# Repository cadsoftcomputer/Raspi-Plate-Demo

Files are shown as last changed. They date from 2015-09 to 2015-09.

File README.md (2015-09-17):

# Raspi-Plate-Demo

This is an H-Bridge and IR LED Pi Hat for controlling the Rasperry Pi with an IR Remote Control.

The following sites were instrumental in setting up LIRC and having Python interface with it.
* https://piface.github.io/pifacecad/lirc.html
* http://alexba.in/blog/2013/01/06/setting-up-lirc-on-the-raspberrypi/
* http://ozzmaker.com/2013/10/24/how-to-control-the-gpio-on-a-raspberry-pi-with-an-ir-remote/

This site helped with setting up the Python script to run on boot.
* http://www.raspberrypi-spy.co.uk/2013/07/running-a-python-script-at-boot-using-cron/

The PiHat standard as defined by the Raspberry Pi Foundation
* https://github.com/raspberrypi/hats

All of the Python code was made to run under Python3 however it's likely that it will run under Python2 since the python-lirc library works in both versions of Python.

The EAGLE design files were made using V7 of EAGLE. The PiHat_Standard_Outline.lbr contains packages that conform to the PiHat standard.

For any questions or concerns contact support@cadsoftusa.com or call 954-237-0932.

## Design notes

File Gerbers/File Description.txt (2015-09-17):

cmp is the Top copper
sol is the Bottom copper
plc is the Top Silkscreen
stc is the Top stop mask
sts is the Bottom Stop mask
drd is the Drill file

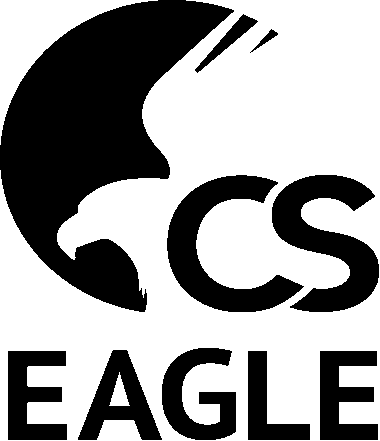
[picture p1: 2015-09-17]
eagle bw_real.bmp

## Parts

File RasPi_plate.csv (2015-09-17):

Qty | Value | Device | Package | Parts | Description | MF | MPN | OC_NEWARK
4 | 0.1u | C-USC0805 | C0805 | C4, C5 | CAPACITOR, American symbol |  | C2012X7R1H104K085AA | 04X3288
2 | 0.22u | C-USC0805 | C0805 | C2 | CAPACITOR, American symbol |  | MC0805B224M250CT | 06R3809
2 | 100 | R-US_R0805 | R0805 | R7 | RESISTOR, American symbol |  | MCHP05W4F1000T5E | 01N6987
8 | 10k | R-US_R0805 | R0805 | R1, R2, R3, R4, R5, R6 | RESISTOR, American symbol |  | RC0805FR-0710KL | 05M4535
10 | 1N4004 | 1N4004 | DO41-10 | D1, D2, D3, D4, D5, D6, D7, D8 | DIODE |  | 1N4007-E3/54 | 05R5987
4 | 1u | C-USC0805 | C0805 | C1, C3 | CAPACITOR, American symbol |  | EMK212B7105KD-T | 77M8435
2 | MCP1700 | MCP1700 | TO92 | IC3 | 1.2V, 1.8V, 2.5V, 2.8V, 3.0V, 3.3V, 5.0V | MICROCHIP | MCP1700-5002E/TO | 34M7415
2 | PIN | 2PINHEADER | 2PINHEAD | J1 | 2-PIN HEADER 2.54mm |  |  | 11P3428
2 | RAS-PI | 40W_PI_HAT_TPH | 2X20 | JP1 | PIN HEADER | SAMTEC | SSW-120-01-G-D | 50M2393
2 | SN754410 | SN754410 | DIL16 | IC1 |  | TEXAS INSTRUMENTS | SN754410NE | 08F8145
2 | TSOP38238 | TSOP38238 | TSOP38238 | IC2 | TSOP38238 IR sensor |  | TSOP38238 | 02P9885
1 | Universal remote control we'll get this locally.

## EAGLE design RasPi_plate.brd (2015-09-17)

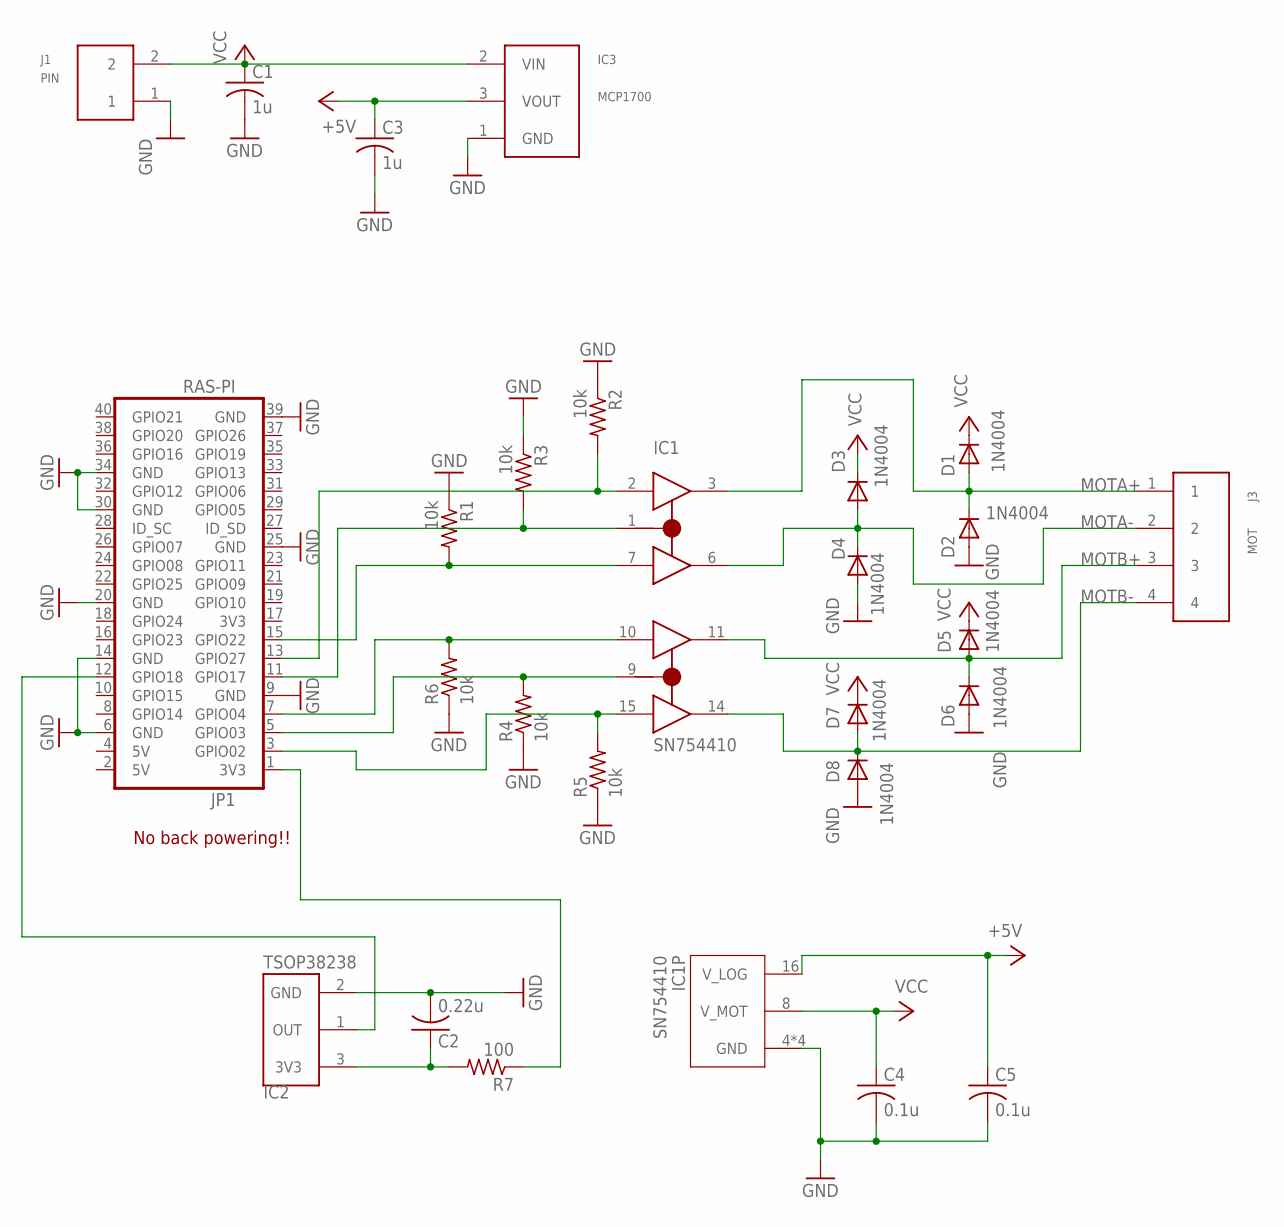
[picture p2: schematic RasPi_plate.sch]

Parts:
C1, C3: 1u; C0805; MPN EMK212B7105KD-T
C2: 0.22u; C0805; MPN MC0805B224M250CT
C4, C5: 0.1u; C0805; MPN C2012X7R1H104K085AA
D1, D2, D3, D4, D5, D6, D7, D8: 1N4004; DO41-10; MPN 1N4007-E3/54
IC1: SN754410; DIL16; MPN SN754410NE
IC2: TSOP38238; MPN TSOP38238
IC3: MCP1700; TO92; MPN MCP1700-5002E/TO
J1: PIN; 2PINHEAD
J3: MOT; 4PINHEAD
JP1: RAS-PI; 2X20
R1, R2, R3, R4, R5, R6: 10k; R0805; MPN MCHP05W4F1002T5E
R7: 100; R0805; MPN MCHP05W4F1000T5E

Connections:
1EN: IC1.1 (1,2EN), JP1.11 (GPIO17), R3.2
+3V3: C3.1, C5.1, IC1.16 (V_LOG), IC3.3 (VOUT)
GND: C1.2, C2.2, C3.2, C4.2, C5.2, D2.A, D4.A, D6.A, D8.A, IC1.4 (GND), IC1.5 (GND), IC1.12 (GND), IC1.13 (GND), IC2.2 (GND), IC3.1 (GND), J1.1, JP1.6 (GND), JP1.9 (GND), JP1.14 (GND), JP1.20 (GND), JP1.25 (GND), JP1.30 (GND), JP1.34 (GND), JP1.39 (GND), R1.1, R2.1, R3.1, R4.1, R5.1, R6.1
MOTA+: D1.A, D2.C, IC1.3 (1Y), J3.1
MOTA-: D3.A, D4.C, IC1.6 (2Y), J3.2
MOTB+: D5.A, D6.C, IC1.11 (3Y), J3.3
MOTB-: D7.A, D8.C, IC1.14 (4Y), J3.4
unnamed: IC1.7 (2A), JP1.15 (GPIO22), R1.2
unnamed: IC1.10 (3A), JP1.7 (GPIO04), R6.2
unnamed: IC1.9 (3,4EN), JP1.5 (GPIO03), R4.2
unnamed: IC2.1 (OUT), JP1.12 (GPIO18)
unnamed: C2.1, IC2.3 (3V3), R7.2
unnamed: JP1.1 (3V3), R7.1
unnamed: IC1.2 (1A), JP1.13 (GPIO27), R2.2
unnamed: IC1.15 (4A), JP1.3 (GPIO02), R5.2
VCC: C1.1, C4.1, D1.C, D3.C, D5.C, D7.C, IC1.8 (V_MOT), IC3.2 (VIN), J1.2

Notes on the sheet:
No back powering!!

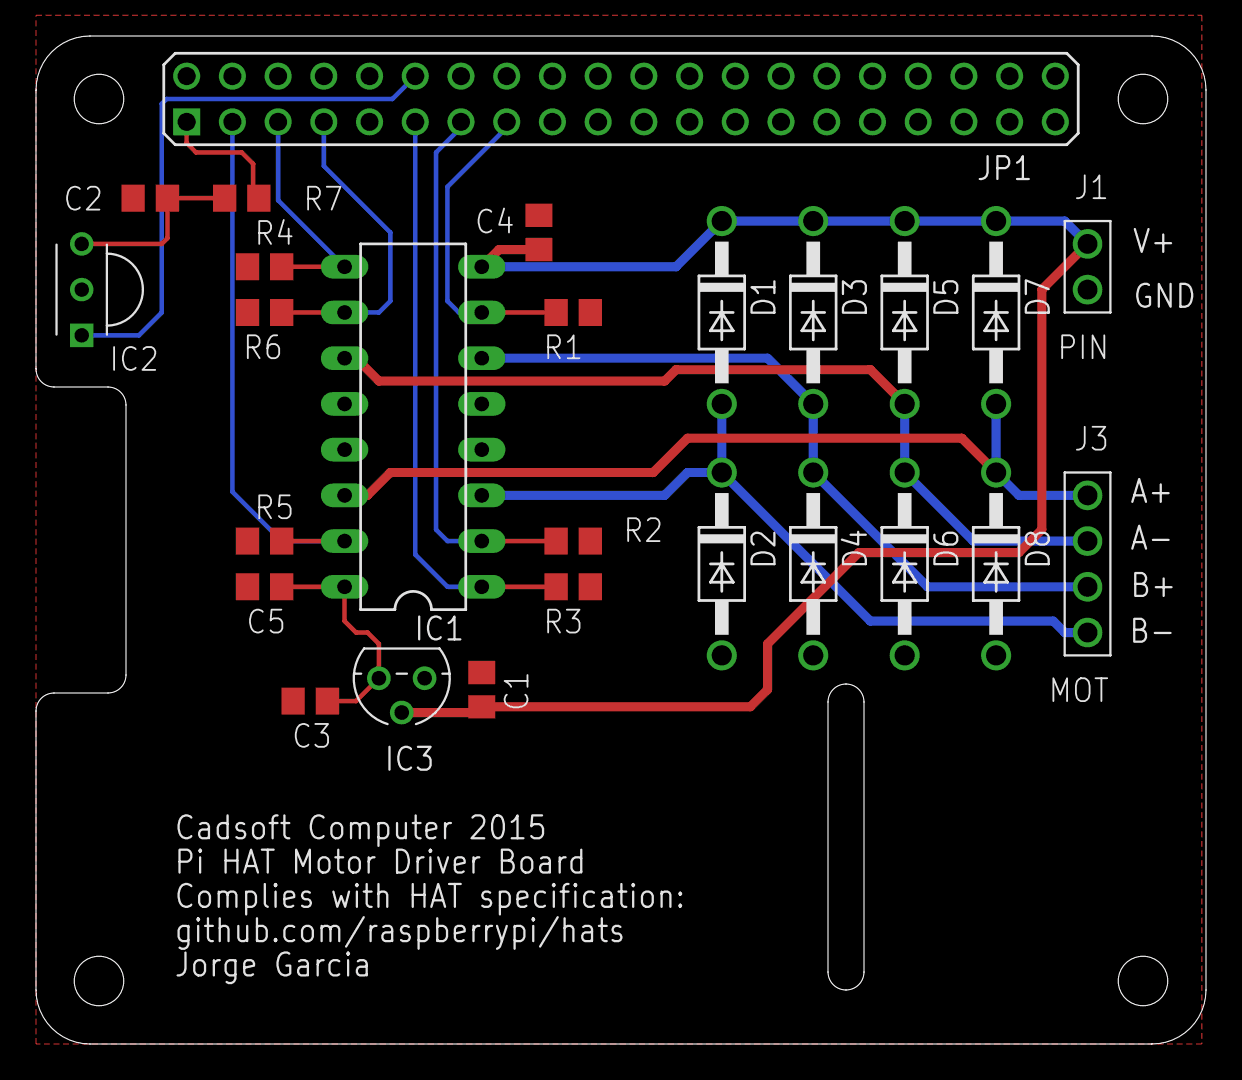
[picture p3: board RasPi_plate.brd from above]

Board: 2 copper layers, 65.0 x 56.0 mm, 27 parts (0 on the bottom side), 16 nets.

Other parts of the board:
U$1: PI_HAT_STANDARD_TPH

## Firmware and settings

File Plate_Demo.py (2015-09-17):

import RPi.GPIO as GPIO
import lirc
import time
import os

#Pin assignments for various signals, following BCM convention
GPIO.setmode(GPIO.BCM)
GPIO.setwarnings(False)		#disable warnings
mot1en = 17
mot1plus = 27
mot1minus = 22
mot2en = 3
mot2plus = 4
mot2minus = 2

allpins = [mot1en, mot1plus, mot1minus, mot2en, mot2plus, mot2minus]

GPIO.setup(allpins, GPIO.OUT)

def stop():
	''' Just cuts all power to motors'''
	GPIO.output(allpins, 0)

def forward(delay):
	''' Moves motors forward for delay seconds'''
	GPIO.output([mot1en, mot1minus, mot2en, mot2plus], 1)
	time.sleep(delay)
	stop()

def backward(delay):
	''' Moves motors backward for delay seconds'''
	GPIO.output([mot1en, mot1plus, mot2en, mot2minus], 1)
	time.sleep(delay)
	stop()

def left(delay):
	''' Moves motors to the left for delay seconds'''
	GPIO.output([mot1en, mot1minus, mot2en, mot2minus], 1)
	time.sleep(delay)
	stop()

def right(delay):
	''' Moves motors to the right for delay seconds'''
	GPIO.output([mot1en, mot1plus, mot2en, mot2plus], 1)
	time.sleep(delay)
	stop()
	
if __name__ == '__main__':
	stop()
	#I'm alive
	forward(2)
	backward(2)
	left(2)
	right(2)
	
	#Start grabbing information from LIRC
	sockid = lirc.init("myprogram", blocking = False)
	
	while True:
		result = lirc.nextcode()		#Returns a list
		if result == []:			#Check for empty list
			command = 'empty'
		else:
			command = result[0]
		
		if command == 'forward':
			forward(0.5)
		elif command == 'back':
			backward(0.5)
		elif command == 'left':
			left(0.5)
		elif command == 'right':
			right(0.5)
		elif command == 'power':
			break
		else:
			continue
	lirc.deinit()
	os.system('shutdown now')

	
	

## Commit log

2015-09-17 First commit
    This commit contains the latest release of the project. It includes the
    eagle design files, Python Script, gebers, and the Raspberry Pi config
    files.
    [RasPi_plate.brd, RasPi_plate.csv, RasPi_plate.sch]
2015-09-17 Raspi-Plate-Demo
    Documentation
